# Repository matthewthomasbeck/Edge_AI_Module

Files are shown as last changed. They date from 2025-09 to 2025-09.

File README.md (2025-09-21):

Edge AI Module Mk-4

# Edge AI Module
### By [Matthew Thomas Beck](https://www.linkedin.com/in/matthewthomasbeck/)

Special thanks to [Omar Ferrer](https://www.linkedin.com/in/omar-ferrer-0bb6355a/) for his help

Click [here](https://www.matthewthomasbeck.com/pages/edge_ai_module.html) for the story behind the build

**Please consider:** if you like it, **star it!**

## Tech Stack
- **Language:** *Python*
- **Libraries:** *threading, queue, time, os, socket, logging, collections.deque, subprocess, signal, sys, random, numpy, opencv-python, openvino, smbus, RPi.GPIO, pigpio, pyserial*
- **Toolkits:** *OpenVino*

## Basic Information

If you want a cheap way to rapidly-prototype a variety of robots, this module may be for you! It will take a bit of work to set up, but you are guaranteed to save much more money as opposed to buying a something like a Jetson board

## **(WIP)** Build For Yourself!

1. Ensure you have these tools:

| **Tools** |
| ----------- |
| 3D Printer (PLA and TPU) |
| Soldering Iron (rosin-core solder) |
| Wire Strippers |
| Lighter/Heat Gun |
| Hex Keys (M2/M3) |
| Good Lighting |

2. Purchase the electronics/components as follows:

| **Components** | **(remember, do your own research to save money)** |
| --- | --- |
| x1 Raspberry Pi 4B | [Amazon](https://www.amazon.com/Raspberry-Pi-Computer-Suitable-Workstation/dp/B0899VXM8F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) |
| x1 Intel NCS2 | [eBay](https://www.ebay.com/sch/i.html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) |
| x1 Pololu 12-Channel Maestro | [Amazon](https://www.amazon.com/Mini-Maestro-12-channel-Servo-Controller/dp/B007MX0ED6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) |
| x1 HiLetgo GY-521 MPU-6050 | [AliExpress](https://www.aliexpress.us/item/3256806865414323.html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) |
| x1 Pi Camera Module 3 (75°) | [AdaFruit](https://www.adafruit.com/product/5657) |
| x1 RadioLink T8S 8 Channels | [Amazon](https://www.amazon.com/Radiolink-Channels-Transmitter-Controller-Rechargeable/dp/B09BTSJN7P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) |
| x1 3.3/5.0V Fan | [AliExpress](https://www.aliexpress.us/item/3256809007098220.html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) |
| x2 LM2596 Buck Converter | [AliExpress](https://www.aliexpress.us/item/2255800279067821.html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) |
| x1 18-Gauge Wire Spool | [Amazon](https://www.amazon.com/BNTECHGO-Silicone-Flexible-Strands-Stranded/dp/B01C5CANVG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) |
| x1 F-F 5V Wire Set | [Amazon](https://www.amazon.com/XLX-Breadboard-Soldering-Brushless-Double-end/dp/B07S62XN5M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) |
| x1 M3 8mm Screws | [Amazon](https://www.amazon.com/Socket-Screws-Bolts-Thread-100pcs/dp/B07CMQ1SQH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) |
| x1 Nylon Screw Set | [Amazon](https://www.amazon.com/Lystaii-Standoff-Motherboard-Standoffs-Assortment/dp/B0BYSHZ2TD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) |
| x1 M3 Brass Inserts | [Amazon](https://www.amazon.com/dp/B07LBQRYR3?ref=ppx_yo2ov_dt_b_product_details&th=1) |
| x1 M2 Brass Inserts | [Amazon](https://www.amazon.com/dp/B0DG8R9XFG?ref=ppx_yo2ov_dt_b_product_details&th=1) |
| x1 Heat-Shrink Tubing Set | [AliExpress](https://www.aliexpress.com/ssr/300000512/BundleDeals2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) |
| x1 Zeee 2S Lipo Batteries | [Amazon](https://www.amazon.com/Zeee-Battery-Connector-Airplane-Helicopter/dp/B08GFRT9S9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) |
| x1 USB-C Vertical Male Plug | [AliExpress](https://www.aliexpress.us/item/3256808930024592.html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) |
| x1 Switch | [AliExpress](https://www.aliexpress.us/item/3256804425729825.html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) |
| x1 XT60H Connector Pairs | [Amazon](https://www.amazon.com/Upgrade-Female-Bullet-Connectors-Battery/dp/B07VRZR5TL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) |
| x1 XT60H Adapter Set | [Amazon](https://www.amazon.com/JIECHUN-Adapter-Connector-Battery-Charger/dp/B0BLHGR17L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) |

3. Print out the 3D components as found in the '3D_parts' folder

4. **(WIP)** Follow this tutorial video here ← (currently making video)

5. Configure OpenVino for Raspberry Pi 4B using 'OpenVino_Setup.txt' (this was VERY hard, take your time)

6. Use the files/functions found in 'utilities' to accelerate development

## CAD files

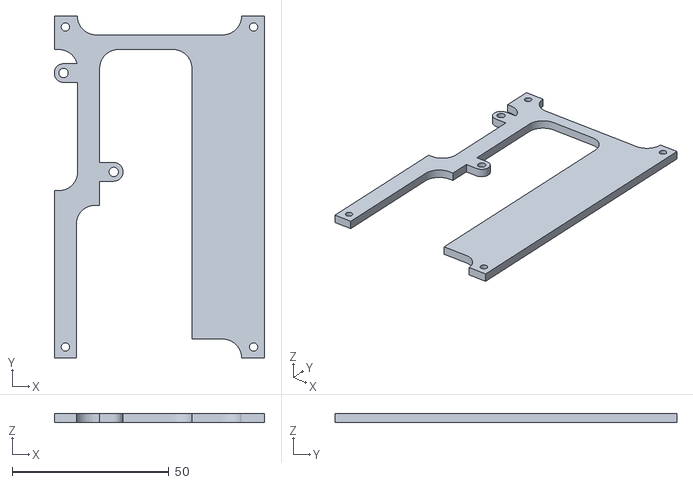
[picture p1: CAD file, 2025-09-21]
3d_parts/ai_module-top_1.8.stl
67.0 x 109.0 x 3.00

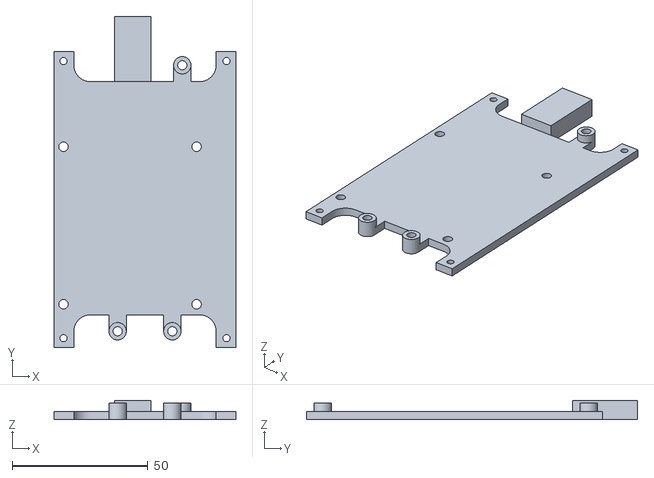
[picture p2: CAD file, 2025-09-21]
3d_parts/ai_module-bottom_1.2.stl
67.0 x 122.0 x 7.00

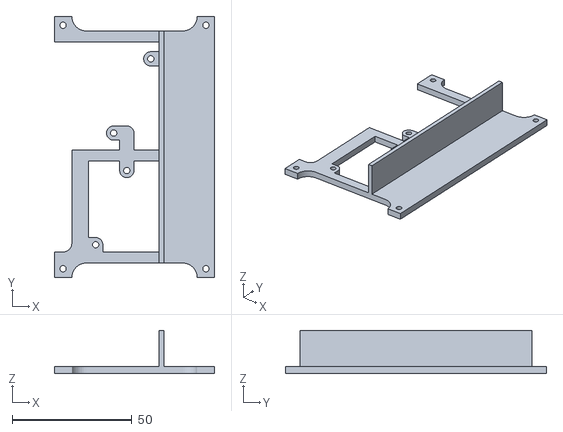
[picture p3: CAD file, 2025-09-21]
3d_parts/ai_module-middle_1.10.stl
67.0 x 109.0 x 18.0

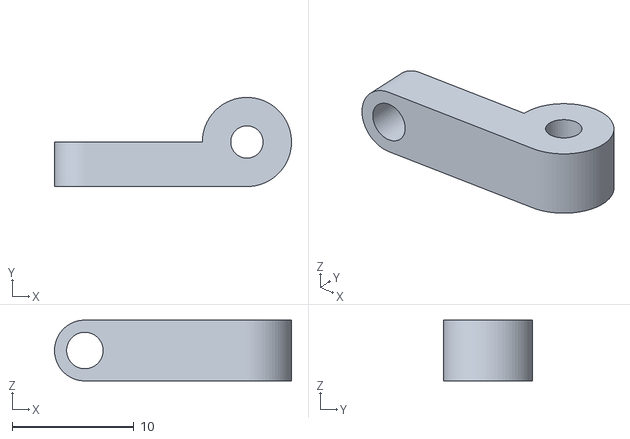
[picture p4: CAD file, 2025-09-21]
3d_parts/ai_module-fanpins_1.0.stl
19.5 x 7.33 x 5.00

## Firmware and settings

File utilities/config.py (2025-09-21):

##################################################################################
# Copyright (c) 2025 Matthew Thomas Beck                                         #
#                                                                                #
# Licensed under the Creative Commons Attribution-NonCommercial 4.0              #
# International (CC BY-NC 4.0). Personal and educational use is permitted.       #
# Commercial use by companies or for-profit entities is prohibited.              #
##################################################################################





##########################################################
############### IMPORT/CREATE DEPENDENCIES ###############
##########################################################


########## IMPORT DEPENDENCIES ##########

##### import necessary libraries #####

import time # import time library for gait timing
import logging # import logging library for debugging





#####################################################
############### CREATE CONFIGURATIONS ###############
#####################################################


########## UTILITY CONFIGURATIONS ##########

##### set logging configuration #####

LOG_CONFIG = {
    'LOG_PATH': "/Robot_Dog/robot_dog.log", # TODO change me!
    'LOG_LEVEL': logging.INFO # set log level to logging.<DEBUG, INFO, WARNING, ERROR, or CRITICAL>
}

########## CAMERA CONFIGURATION ##########

##### set camera configuration #####

CAMERA_CONFIG = {
    'FOV': 75, # degrees
    'CAMERA_WIDTH': 4608,
    'CAMERA_HEIGHT': 2592,
    'FOV_HORIZONTAL': 66,  # degrees
    'FOV_VERTICAL': 41,  # degrees
    'PIXEL_SIZE_UM': 1.4,  # pixel size in micrometers
    'DEPTH_OF_FIELD': 0.1,  # depth of field distance in meters
    'APERTURE_RATIO': 1.8,
    'WIDTH': 640, # width of the camera image
    'HEIGHT': 480, # height of the camera image
    'FRAME_RATE': 30, # frame rate of the camera in frames per second
    'CROP_FRACTION': 0.5, # fraction of the image to crop from each side (0.0 to 1.0)
    'OUTPUT_WIDTH': 128, # width of the ML image
    'OUTPUT_HEIGHT': 48, # height of the image for ML inference
}


########## INFERENCE CONFIGURATIONS ##########

##### set ML configurations #####

INFERENCE_CONFIG = {
    'TPU_NAME': "MYRIAD",  # literal device name in code
    'MODEL_PATH': "/home/matthewthomasbeck/Projects/Robot_Dog/model/person-detection-0200.xml",  # TODO change me!
}


########## ROBOT CONTROL CONFIGURATIONS (internet and radio) ##########

##### declare movement channel GPIO pins #####

SIGNAL_TUNING_CONFIG = { # dictionary of signal tuning configuration for sensitivity
    'JOYSTICK_THRESHOLD': 40, # number of times condition must be met to trigger a request on a joystick channel
    'TOGGLE_THRESHOLD': 40, # number of times condition must be met to trigger a request on a button channel
    'TIME_FRAME': 0.10017, # time frame for condition to be met, default: 0.100158
    'DEADBAND_HIGH': 1600, # deadband high for PWM signal
    'DEADBAND_LOW': 1400 # deadband low for PWM signal
}

##### set receiver channels #####

RECEIVER_CHANNELS = { # dictionary of receiver channels' names, GPIO pins, and states
    'channel_0': {'name': 'tilt_up_down', 'gpio_pin': 17, 'counter': 0, 'timestamp': time.time()},
    'channel_1': {'name': 'trigger_shoot', 'gpio_pin': 27, 'counter': 0, 'timestamp': time.time()},
    'channel_2': {'name': 'squat_up_down', 'gpio_pin': 22, 'counter': 0, 'timestamp': time.time()},
    'channel_3': {'name': 'rotate_left_right', 'gpio_pin': 5, 'counter': 0, 'timestamp': time.time()},
    'channel_4': {'name': 'look_up_down', 'gpio_pin': 6, 'counter': 0, 'timestamp': time.time()},
    'channel_5': {'name': 'move_forward_backward', 'gpio_pin': 13, 'counter': 0, 'timestamp': time.time()},
    'channel_6': {'name': 'shift_left_right', 'gpio_pin': 19, 'counter': 0, 'timestamp': time.time()},
    'channel_7': {'name': 'extra_channel', 'gpio_pin': 26, 'counter': 0, 'timestamp': time.time()},
}

##### set receiver configuration #####

MAESTRO_CONFIG = {
    'SERIAL_PATH': "/dev/serial0", # set serial port name to first available
    'SERIAL_BAUD_RATE': 9600, # set baud rate for serial connection
    'SERIAL_TIMEOUT': 1 # set timeout for serial connection
}


########## PHYSICAL CONFIGURATION ##########

##### set accelerometer configuration #####

ACCELEROMETER_CONFIG = { # dictionary of accelerometer configuration

    'MPU_6050_ADDRESS': 0x68, # address of the accelerometer
    'PWR_MGMT_1': 0x6B, # power management register
    'SMPLRT_DIV': 0x19, # sample rate divider
    'CONFIG_REGISTER': 0x1A, # configuration register
    'GYRO_CONFIG': 0x1B, # gyro configuration register
    'INT_ENABLE': 0x38, # interrupt enable register
    'ACCEL_XOUT_H': 0x3B, # accelerometer x-axis output high register
    'ACCEL_YOUT_H': 0x3D, # accelerometer y-axis output high register
    'ACCEL_ZOUT_H': 0x3F, # accelerometer z-axis output high register
    'GYRO_XOUT_H': 0x43, # gyroscope x-axis output high register
    'GYRO_YOUT_H': 0x45, # gyroscope y-axis output high register
    'GYRO_ZOUT_H': 0x47 # gyroscope z-axis output high register
}
